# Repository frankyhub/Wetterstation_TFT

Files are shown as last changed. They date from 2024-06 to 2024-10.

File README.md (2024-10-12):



<div align="center">

|[:skull:ISSUE](https://github.com/frankyhub/Wetterstation_TFT/issues?q=is%3Aissue)|[:speech_balloon: Forum /Discussion](https://github.com/frankyhub/Wetterstation_TFT/discussions)|[:grey_question:WiKi](https://github.com/frankyhub/Wetterstation_TFT/wiki)||
|--|--|--|--|
| | | | |
||<a href="https://github.com/frankyhub/Wetterstation_TFT/issues">|<a href="https://github.com/frankyhub/Wetterstation_TFT/discussions">|<a href="https://github.com/frankyhub/Wetterstation_TFT/releases">|
|| <a href="https://github.com/frankyhub/Wetterstation_TFT/pulse" alt="Activity">| <a href="https://github.com/frankyhub/Wetterstation_TFT/graphs/traffic">  |<a href="https://github.com/frankyhub?tab=stars"> |
</div>

# Wetterstation_TFT
ESP32 Wetterstation mit WLAN-Manager - Wetterdaten Tegernsee und Raumklima, 1.77" TFT Display

## Story:
Diese Anleitung beschreibt den Aufbau einer Wetterstation in einem Holzgehäuse mit einem ESP32. Beim ESP32 ist ein DHT11-Sensor und einem TFT Display 1.77" angeschlossen. Die Wetterstation beinhaltet einen WiFi-Manager für die Einstellung der WLAN-Zugangsdaten (SSID und Passwort). Nach den ersten Start der Wetterstation, muss in den WLAN-Einstellungen des Handy oder Tablet das Netzwerk "Wetterstation" ausgewählt und über einen Browser die IP-Adresse 192.168.4.1 aufgerufen werden. Danach startet die "Wetterstation WLAN-Einstellung" und die Zugangsdaten für das WLAN können eingetragen werden. Sind die Zugangsdaten korrekt, startet die Wetterstation.
Die Wetterstation zeigt beim Start für 5 Sekunden einen Smiley. In dieser Zeit werden die aktuelle Uhrzeit, das Datum und die aktuellen Wetterdaten aus der Region Tegernsee von de.pool.ntp.org und von openweathermap.org geladen.
Sind die Daten geladen, verschwindet der Smiley und es werden in regelmäßigen Abständen drei Seiten mit Datum und Uhrzeit, danach das Raumklima mit Temperatur und Luftfeuchte, zuletzt die Wetterdaten Außen-Temperatur, Windgeschwindigkeit und Luftdruck angezeigt.

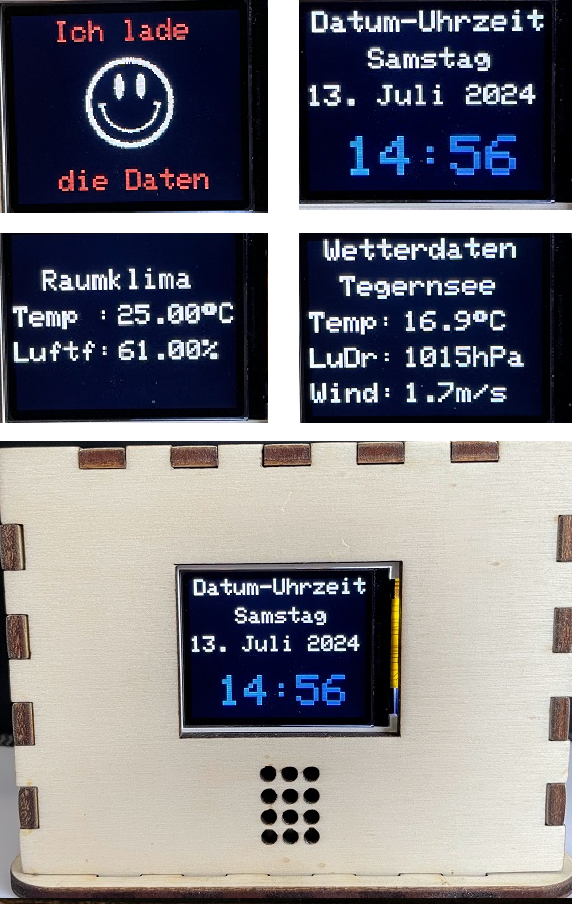
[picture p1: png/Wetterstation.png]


## Hardware:
Das benötigen wir für die Wetterstation:

| Anzahl | Bezeichnung | 
| --- | --- |
| 1 | ESP32 |
| 1 | ESP32-Shield | 
| 1 | ESP32 Stiftleiste | 
| 1 | DHT11-Sensor | 
| 1 | 10k Widerstand | 
| 1 | TFT Display 1.77" | 
| 1 | 8V Netzteil | 
| 1 | Sperrholzplatte 4mm x 600x300 | 
| 1 | 3D-Druck Teile für den ESP32, das OLED-Display und den DHT11 | 
| 1 | Schaltdraht | 
| 1 | Sekundenkleber | 
| 1 | Holzkleber |
| -------- | -------- | 

## Der Aufbau erfolgt in 5 Schritten:

1. Schritt Verdrahten

+ Wir löten auf das ESP32-Shield die Stiftleisten
+ Am ESP32-Shield wird ein 10kΩ Pullupwiderstand gegen +5V angelötet
+ Wir schließen mit Schaltdraht den DHT11-Sensor am ESP32-Shield GPIO27 an
+ Wir verdrahten den DHT11 mit +5V und GND
+ Wir verbinden mit Schaltdraht den ESP32 mit dem Display
+ Ist der ESP32 auf dem Shield, der Sensor und das Display angelötet, erfolgt der erste Test

| ESP32 | 1.77" TFT | 
| --- | --- |
|  GND | GND |
| 5V |  VCC |
|  G18 |  SCK |
| G23 |  SDA (MOSI) |
| G14 |  RES (RST) |
| G13 |  RS (DC) |
| G12 |  CS |
| 3.3V | LEDA |
| --- | ---  |

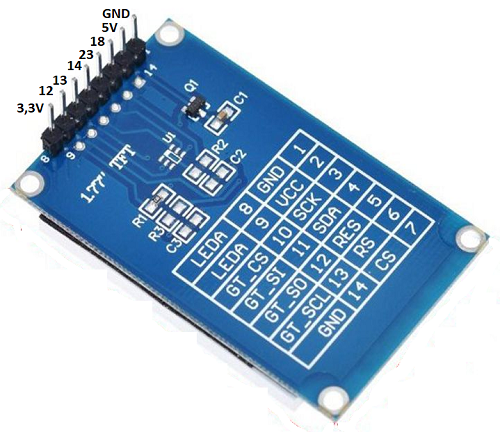
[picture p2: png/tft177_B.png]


| ESP32 | 1.8" TFT | 
| --- | --- |
|  GND | GND |
| 5V |  VCC |
|  G18 |  SCK |
| G23 |  SDA (MOSI) |
| G14 |  RESET |
| G13 |  A0 |
| G12 |  CS |
| 3.3V | LED |
| --- | ---  |

Stiftleisten einlöten:
  
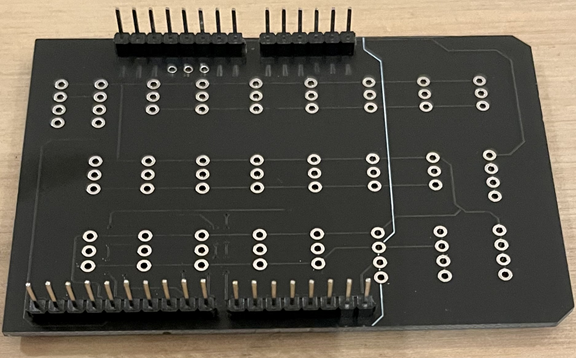
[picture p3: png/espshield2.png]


DHT11 anlöten:

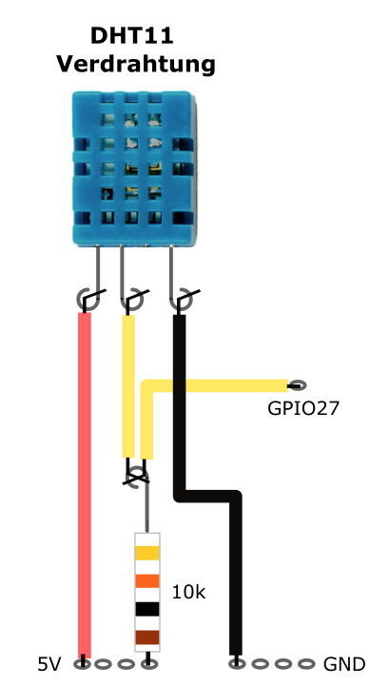
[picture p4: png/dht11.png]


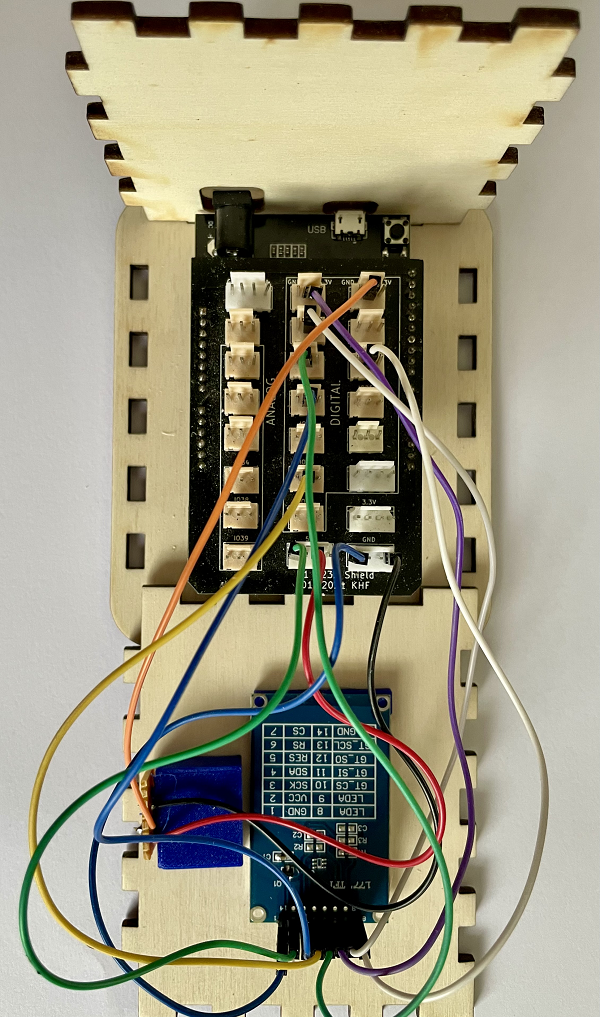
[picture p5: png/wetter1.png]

---

2. Schritt 3D-Druckteile zeichnen und drucken

+ 3D-Druckteile zeichnen und drucken
+ 4 x ESP32-Pins d=5mm h=7mm
+ 1 x DHT11-Halterung 24x8x21 mit DHT11 Aussparung

---

3. Schritt Gehäuse lasern

+ Wir erstellen mit [BOXES.PY](https://festi.info/boxes.py/) eine Lasercutter Vorlage
+ Wähle die ClosedBox - Fully closed box mit den Maßen x=110, y=90, h=90 und thickness=4
+ Zusätzlich werden runde Öffnungen für den DHT11-Sensor in der Frontseinte,
+ eine Aussparung für das TFT-Display und
+ zwei Aussparungen für den Spannungs- und Programmieranschluss des ESP32 in der Seitenwand eingefügt

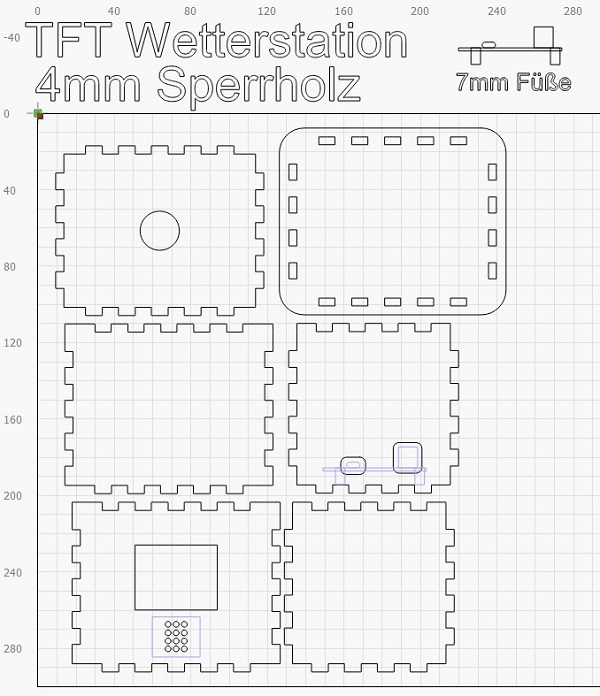
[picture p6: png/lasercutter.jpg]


---

4. Schritt Montage

+ Mit Sekundenkleber die 3D-Druck Bauteilfüße auf den ESP32 kleben
+ Das TFT-Display auf die Frontseite kleben
+ Die DHT11-Halterung an die Front-Innenseite kleben
+ Den ESP32 zu den Aussparungen der Seitenwand justieren und auf die Grundplatte kleben
+ Vor dem finalen verkleben des Gehäuses erfolgt ein Funktionstest
+ War der Funktionstest erfolgreich, kann das Gehäuse vollständig verklebt werden

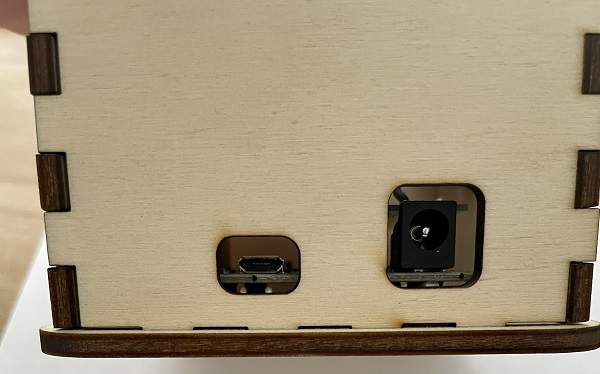
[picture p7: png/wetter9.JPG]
  

Erster Funktionstest am Seriellen Monitor:

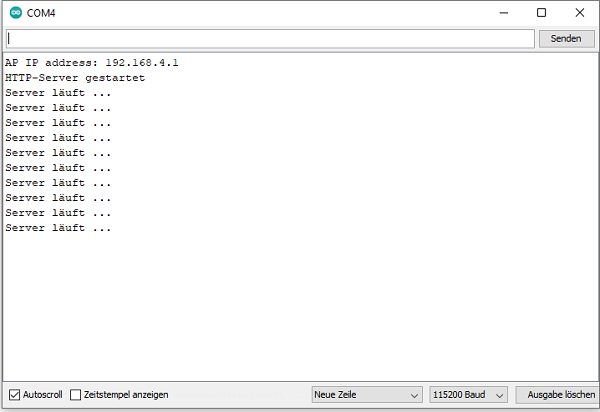
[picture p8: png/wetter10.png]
  

---

5. Schritt Inbetriebnahme

+ Im Handy oder Tablet die WLAN-Einstellungen öffnen
+ Das Netzwerk "Wetterstation" aufrufen
+ Im Browser die IP-Adresse 192.168.4.1 aufrufen
+ Die Seite "Wetterstation WLAN Einstellung" öffnet sich
+ Die WLAN-Zugangsdaten SSID und Passwort eingeben und speichern
+ Der Zeitserver ist voreingestellt und muss nicht verändert werden
+ Ist die WLAN-Verbindung korrekt, startet die Wetterstation mit einem Smiley am Display
+ Danach werden abwechselnd das aktuelle Datum mit Uhrzeit, danach das Raumklima mit Temperatur und Luftfeuchte und die aktuellen Wetterdaten aus der Region Tegernsee angezeigt
+ Die angezeigten Daten wechseln in regelmäßigen Abständen

Aufruf "Wetterstation" in den WLAN-Einstellungen

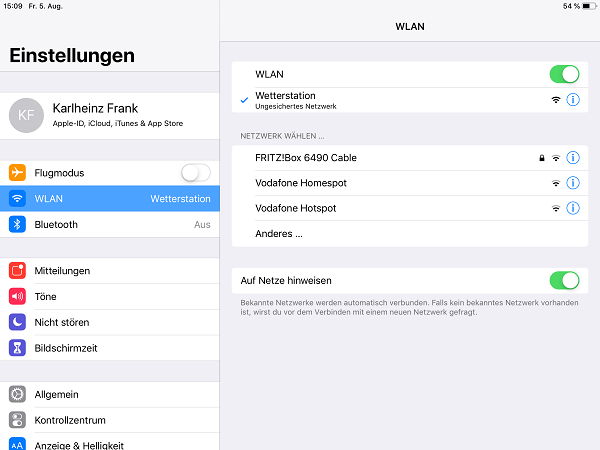
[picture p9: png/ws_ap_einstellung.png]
  

Im Browser die IP-Adresse 192.168.4.1 öffnen, die WLAN Zugangsdaten eingeben und speichern

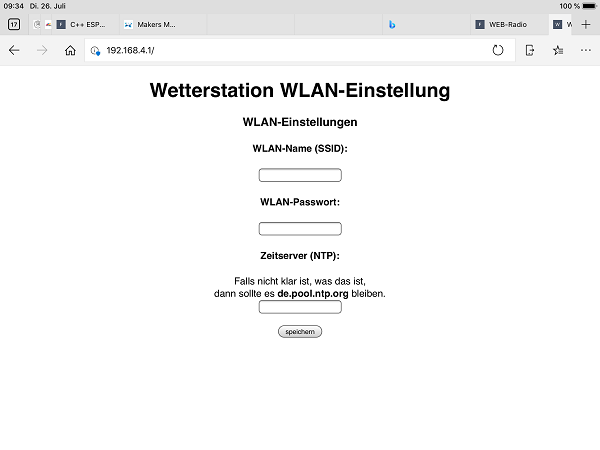
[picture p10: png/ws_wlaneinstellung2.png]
  

Sind die WLAN-Zugangsdaten korrekt, startet die Wetterstation

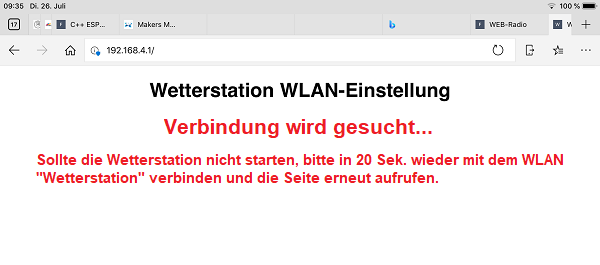
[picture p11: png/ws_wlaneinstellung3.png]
  

Startet die Wetterstation nicht, muss der Vorgang wiederholt werden.
Kontrolle am Seriellen Monitor:

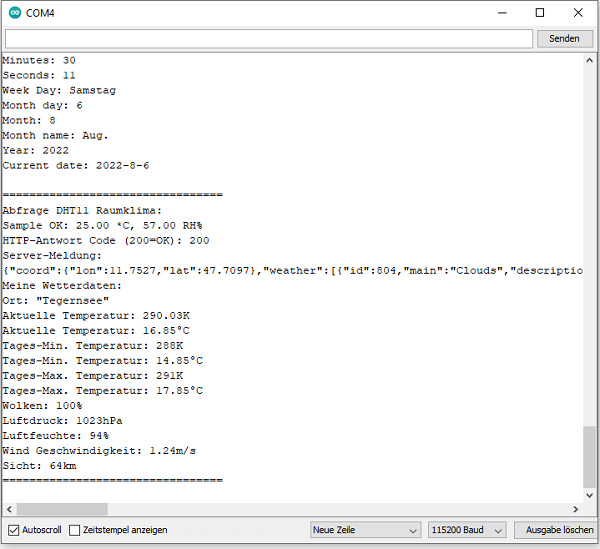
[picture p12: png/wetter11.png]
  

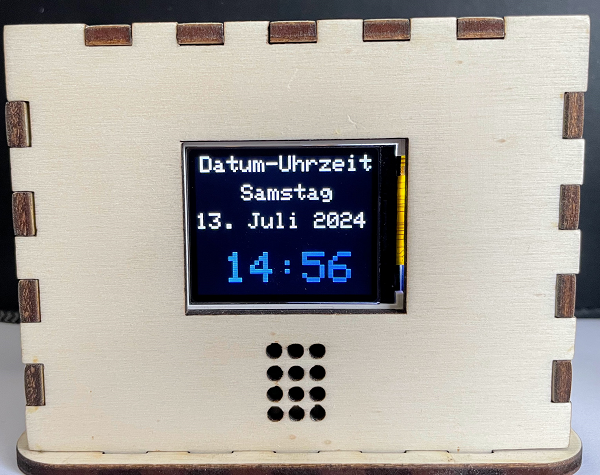
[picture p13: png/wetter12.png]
  

Fertig, Glückwunsch!

---

## Troubleshooting, mögliche Fehlerursachen

+ Sichtkontrolle - sind alle Lötstellen ok?
+ Sind Lötbrücken zusehen oder sind Bauteilfüße fälschlicherweise mit einander verbunden?
+ Sitzt der ESP32 korrekt auf dem Shield? Auf die Polung achten und und Bauteilfüße kontrollieren.
+ Sind die Anschlussdrähte zum Sensor und Display ok?
+ Ist die Spannungsversorgung für den ESP32 ok?
+ Wurde das Programm korrekt geladen? Meldung: Hochladen abgeschlossen.
+ Wird das Display vom ESP32 erkannt? Mit dem I²C-Scanner prüfen.
+ Werden die Sensordaten und die Uhrzeit/Datum ausgelesen? Mit dem Seriellen Montitor der Arduino IDE prüfen.
+ Wurden die WLAN-Zugangsdaten korrekt eingegeben?

---

## Abkürzungen

+ TFT Display -Thin-film transistor-Display, Anzeige mit Dünnschichttransistor-Ansteuerung
+ u8g2 Library - Universal 8Bit Graphics Library
+ I²C - Inter-Integrated Circuit (Serieller Datenbus)
+ SCL - Serial Clock
+ SDA - Serial Data

---

## Setup_User.h

Die Setup_User.h in C:\Users\User\Documents\Arduino\libraries\TFT_eSPI\ kopieren!!!!!

```C++
// TFT 1.77" 1.8" Library

#define ST7735_DRIVER
#define TFT_WIDTH 128
#define TFT_HEIGHT 160
#define ST7735_REDTAB
#define TFT_BACKLIGHT_ON HIGH // HIGH or LOW are options

// ###### EDIT THE PIN NUMBERS IN THE LINES FOLLOWING TO SUIT YOUR ESP32 SETUP ######
#define TFT_MOSI 23
#define TFT_SCLK 18
#define TFT_CS 17 // Chip select control pin
#define TFT_DC 2 // Data Command control pin
#define TFT_RST 14 // Reset pin (could connect to RST pin)

#define LOAD_GLCD   // Font 1. Original Adafruit 8 pixel font needs ~1820 bytes in FLASH
#define LOAD_FONT2  // Font 2. Small 16 pixel high font, needs ~3534 bytes in FLASH, 96 characters
#define LOAD_FONT4  // Font 4. Medium 26 pixel high font, needs ~5848 bytes in FLASH, 96 characters
#define LOAD_FONT6  // Font 6. Large 48 pixel font, needs ~2666 bytes in FLASH, only characters 1234567890:-.apm
#define LOAD_FONT7  // Font 7. 7 segment 48 pixel font, needs ~2438 bytes in FLASH, only characters 1234567890:-.
#define LOAD_FONT8  // Font 8. Large 75 pixel font needs ~3256 bytes in FLASH, only characters 1234567890:-.
#define LOAD_GFXFF  // FreeFonts. Include access to the 48 Adafruit_GFX free fonts FF1 to FF48 and custom fonts

// Comment out the #define below to stop the SPIFFS filing system and smooth font code being loaded
// this will save ~20kbytes of FLASH
#define SMOOTH_FONT
#define SPI_FREQUENCY  27000000 // Actually sets it to 26.67MHz = 80/3

// Optional reduced SPI frequency for reading TFT
#define SPI_READ_FREQUENCY  20000000

// The XPT2046 requires a lower SPI clock rate of 2.5MHz so we define that here:
#define SPI_TOUCH_FREQUENCY  2500000

// Transactions are automatically enabled by the library for an ESP32 (to use HAL mutex)
// so changing it here has no effect

// #define SUPPORT_TRANSACTIONS

//-------- END ----------------

```

---

<div style="position:absolute; left:2cm; ">   
<ol class="breadcrumb" style="border-top: 2px solid black;border-bottom:2px solid black; height: 45px; width: 900px;"> <p align="center"><a href="#oben">nach oben</a></p></ol>
</div>  

---

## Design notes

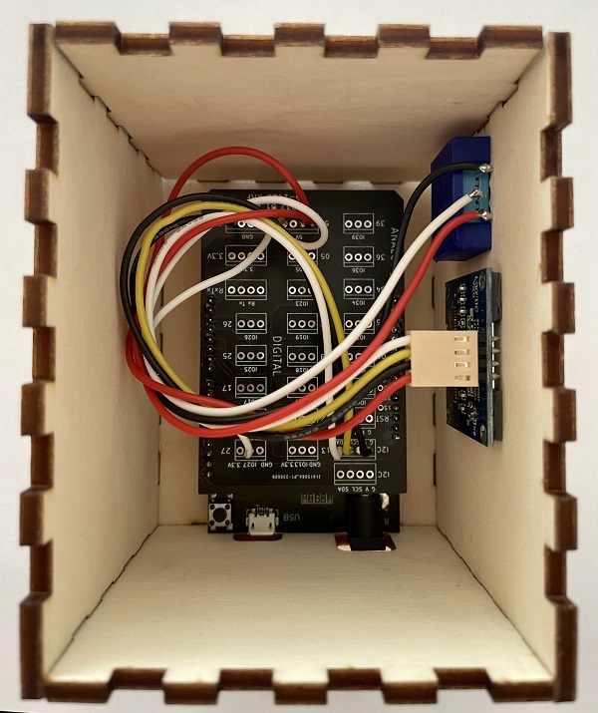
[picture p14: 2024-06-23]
png/wetter8.JPG

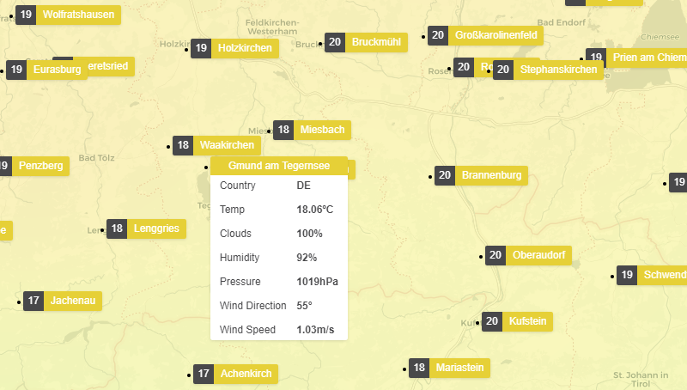
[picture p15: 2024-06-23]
png/13wetter.png

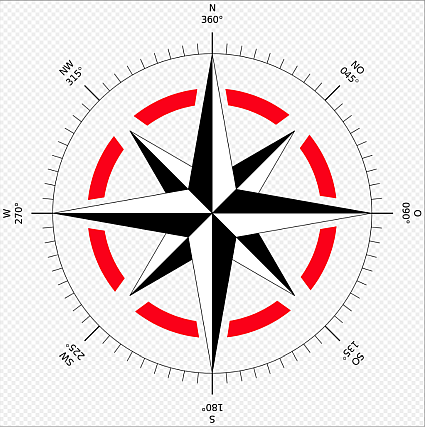
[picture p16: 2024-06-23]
png/14wetter.png

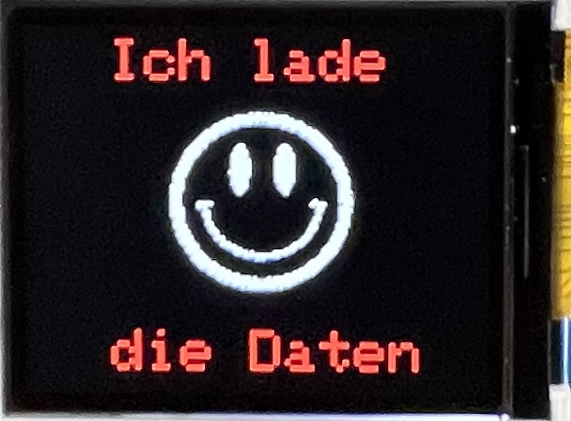
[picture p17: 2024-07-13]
png/ladedaten.png

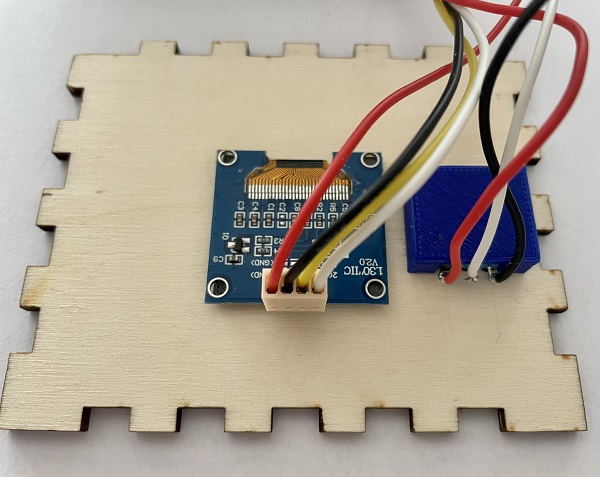
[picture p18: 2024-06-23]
png/wetter7.JPG

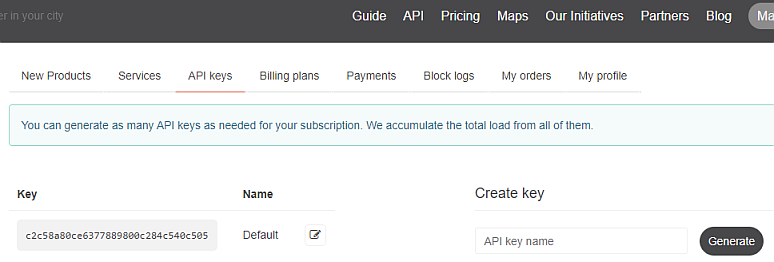
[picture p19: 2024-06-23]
png/11wetter.png

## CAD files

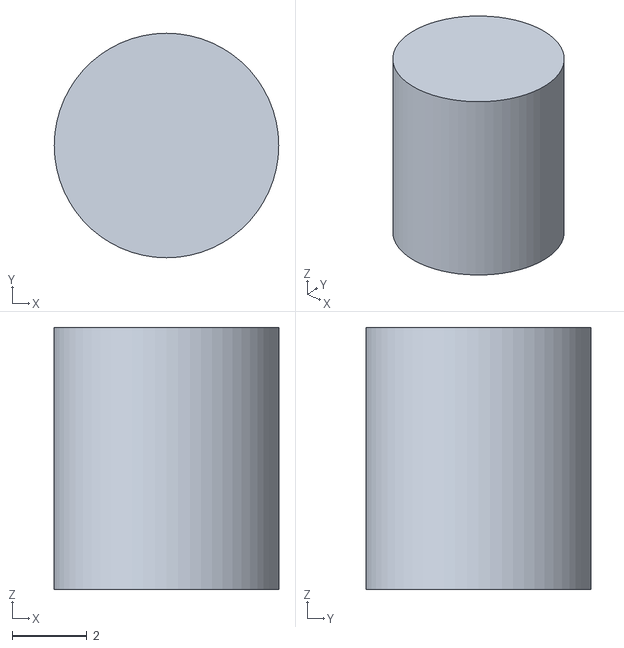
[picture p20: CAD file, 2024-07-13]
3D/ESP32-PIN7mm.stl
6.00 x 6.00 x 7.00

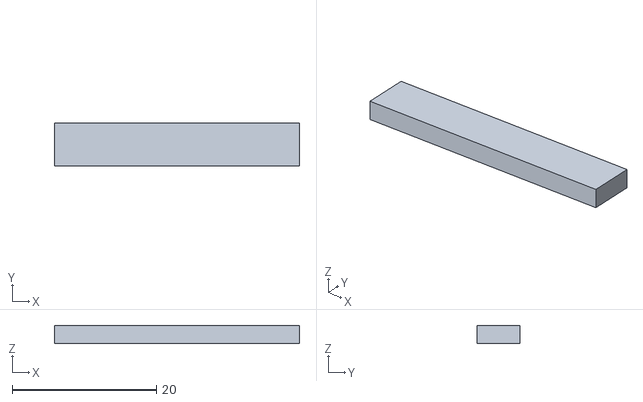
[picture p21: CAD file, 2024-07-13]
3D/TFT-Spacer.stl
34.0 x 6.00 x 2.50

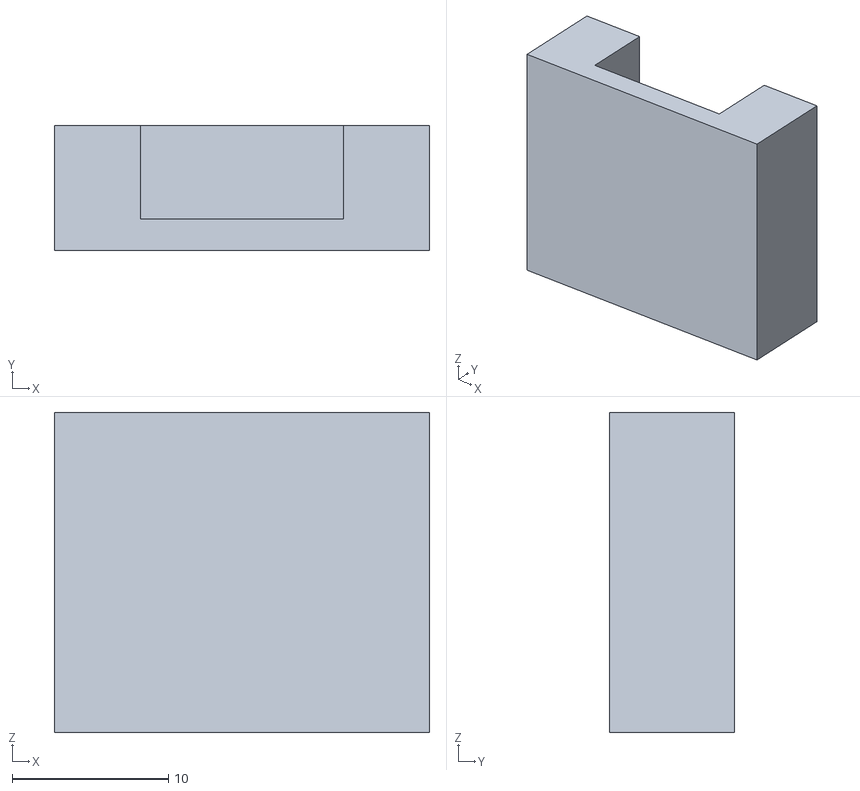
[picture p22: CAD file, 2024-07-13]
3D/DHT11-Halter.stl
24.0 x 8.00 x 20.5

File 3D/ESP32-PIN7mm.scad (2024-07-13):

//Platinen Pin ESP32 UNO Wetterstation
//4x

$fn=60;
Rgr = 3; //Radius PIN 
R1kl = 0; //Radius 1 Stift
R2kl = 0; //Radius 2 Stift
Sh = 7;       //Sockelhöhe


cylinder(h = Sh, r1=Rgr , r2=Rgr , center = true);
translate(v = [0, 0, Sh/2])
cylinder(h = 3, r1 = R1kl, r2 = R2kl, center = true);

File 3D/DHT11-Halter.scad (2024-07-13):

//DHT11-Halterung

difference() {
cube(size = [24,8,20.5], center = true);

translate(v = [-6.5, -2, -8])
cube(size = [13,7,18.5]);
   
}

/*
translate(v = [-12, -4, 10])
cube(size = [24,4,1.5]);

translate(v = [-10, -2, -8])
color( "red", 1.0 )
cube(size = [12.5,5.8,18]);
*/

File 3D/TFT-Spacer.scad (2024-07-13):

cube(size = [34,6,2.5], center = true);

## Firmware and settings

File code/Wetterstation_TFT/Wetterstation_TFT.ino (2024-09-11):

/*************************************************************************************************
                                      PROGRAMMINFO
**************************************************************************************************
  Funktion: ESP32 Wetterstation mit WLAN-Manager - Wetterdaten Tegernsee und Raumklima DHT11 TFT 1.77"
            Gas-Sensor MQ135, Buzzer und Gas LED-Ampel
            Automatische So/Wi-Zeit Umstelung
  OpenWeather API 31.10.2022: Wetterstation_AP    b2bc7fc61c4cc3545e6bbf151b58e1dd

**************************************************************************************************
  Version: 11.09.2024
**************************************************************************************************
  Board: ESP32vn IoT UNO V1.0.4 /1.0.6

**************************************************************************************************
  C++ Arduino IDE V1.8.19
**************************************************************************************************
  Einstellungen:
  https://dl.espressif.com/dl/package_esp32_index.json
  http://dan.drown.org/stm32duino/package_STM32duino_index.json
  https://raw.githubusercontent.com/espressif/arduino-esp32/gh-pages/package_esp32_dev_index.json
**************************************************************************************************

  Server-Abfrage Programm:
  http://api.openweathermap.org/data/2.5/weather?q=Tegernsee,DE&APPID=c2c58a80ce6377889800c284c540c505

  Server-Abfrage 2. API:
  http://api.openweathermap.org/data/2.5/weather?q=Tegernsee,DE&APPID=b2bc7fc61c4cc3545e6bbf151b58e1dd

  JSON-Meldung:
  {"coord":{"lon":11.7527,"lat":47.7097},
  "weather":
  [{"id":804,"main":"Clouds","description":"overcast clouds","icon":"04d"}],

  "base":"stations",
  "main":
  {"temp":288.35,
  "feels_like":288.54,
  "temp_min":285.19,
  "temp_max":291.7,
  "pressure":1016,
  "humidity":100,
  "sea_level":1016,
  "grnd_level":932},
  "visibility":273,
  "wind":{"speed":1.75,"deg":30,"gust":3.01},

  "clouds":{"all":100},
  "dt":1625628595,
  "sys":{"type":2,"id":2001431,"country":"DE","sunrise":1625628176,"sunset":1625685150},
  "timezone":7200,"id":2823679,"name":"Tegernsee","cod":200


  *********************************************  MQ-135 Luftqualität-Sensor  ******************************************************
  Beschreibung des MQ-135 Luftqualität-Sensor

  Sensor zum Messen der Konzentration von verschiedenen Giftgasen wie Benzon, Alkohol, Rauch sowie
  Verunreinigungen in der Luft. Der MQ-135 misst eine Gaskonzentration von 10 bis 1000ppm und ist ideal zum Erkennen eines
  Gaslecks, als Gas-Alarm oder für sonstige Robotik- und Microcontroller-Projekte.

  Die Sensoren der MQ-Serie benutzen ein kleines Heizelement mit einem elektronisch-chemischen Sensor. Sie sind empfindlich
  gegenüber verschiedenster Gase und eignen sich zur Verwendung in Räumen.

  Der Sensor hat eine hohe Empfindlichkeit und schnelle Reaktionszeit, benötigt allerdings einige Minuten bis er genaue Messwerte
  ausgibt, da der Sensor sich erst aufheizen muss. Die Messwerte des Sensors werden als analoger Wert ausgegeben, welcher mit einem
  Microcontroller einfach ausgewertet werden kann.

  Pinbelegung:

  VCC - Stromversorgung 5V
  GND - Masseanschluss
  AOUT - Analoger Output
  DOUT -  Digitaler Output
  Zum Einstellen des Schwellenwerts besitzt das Modul ein Potentiometer. Am digitalen Pin gibt der Sensor lediglich eine 0 oder 1 aus,
  je nach dem ob der eingestellte Schwellenwert überschritten wird.

  Vorsicht: Der Sensor wird im Betrieb warm!

  Details:
  Auflösung: 10~1000ppm
  Sensitive Widerstand: 2KΩ to 20KΩ in 100ppm CO
  Genauigkeit: ≥ 3%
  Reaktionszeit: ≤ 1s
  Ansprechzeit nach Einschalten: ≤ 30s
  Heizstrom: ≤ 180mA
  Heizspannung: 5.0V±0.2V / 1.5±0.1V
  Eingangsspannung: 5V
  Heizenergieleistung ca.: 350mW
  Abmessungen: ca. 30mm (Länge) * 20mm (Breite)


  !!!!!!!!!!!!!!!!! /TFT_eSPI/User_Setup.h !!!!!!!!!!!!!!!!!!!!!!!!!!!!!!!!!!!!!!

  // TFT 1.77" Library

  #define ST7735_DRIVER
  #define TFT_WIDTH 128
  #define TFT_HEIGHT 160
  #define ST7735_REDTAB
  #define TFT_BACKLIGHT_ON HIGH // HIGH or LOW are options

  // ###### EDIT THE PIN NUMBERS IN THE LINES FOLLOWING TO SUIT YOUR ESP32 SETUP ######
  #define TFT_MOSI 23
  #define TFT_SCLK 18
  #define TFT_CS 12 // Chip select control pin
  #define TFT_DC 13 // Data Command control pin
  #define TFT_RST 14 // Reset pin (could connect to RST pin)

  #define LOAD_GLCD   // Font 1. Original Adafruit 8 pixel font needs ~1820 bytes in FLASH
  #define LOAD_FONT2  // Font 2. Small 16 pixel high font, needs ~3534 bytes in FLASH, 96 characters
  #define LOAD_FONT4  // Font 4. Medium 26 pixel high font, needs ~5848 bytes in FLASH, 96 characters
  #define LOAD_FONT6  // Font 6. Large 48 pixel font, needs ~2666 bytes in FLASH, only characters 1234567890:-.apm
  #define LOAD_FONT7  // Font 7. 7 segment 48 pixel font, needs ~2438 bytes in FLASH, only characters 1234567890:-.
  #define LOAD_FONT8  // Font 8. Large 75 pixel font needs ~3256 bytes in FLASH, only characters 1234567890:-.
  #define LOAD_GFXFF  // FreeFonts. Include access to the 48 Adafruit_GFX free fonts FF1 to FF48 and custom fonts

  // Comment out the #define below to stop the SPIFFS filing system and smooth font code being loaded
  // this will save ~20kbytes of FLASH
  #define SMOOTH_FONT
  #define SPI_FREQUENCY  27000000 // Actually sets it to 26.67MHz = 80/3

  // Optional reduced SPI frequency for reading TFT
  #define SPI_READ_FREQUENCY  20000000

  // The XPT2046 requires a lower SPI clock rate of 2.5MHz so we define that here:
  #define SPI_TOUCH_FREQUENCY  2500000

  // Transactions are automatically enabled by the library for an ESP32 (to use HAL mutex)
  // so changing it here has no effect

  // #define SUPPORT_TRANSACTIONS

 **************************************************************************************************/


#include <Arduino.h>
#include <U8g2lib.h>
#include <Wire.h>


U8G2_SH1106_128X64_NONAME_F_HW_I2C u8g2(U8G2_R0, /* reset=*/ U8X8_PIN_NONE);
unsigned long delayTime;

//******** TFT ************************************
// New background colour
#define TFT_BROWN 0x38E0

// Pause in milliseconds between screens, change to 0 to time font rendering
#define WAIT 2000

#include <TFT_eSPI.h> // Graphics and font library for ST7735 driver chip
#include <SPI.h>
TFT_eSPI tft = TFT_eSPI();  // Aktualisiere User_Setup.h

unsigned long targetTime = 0; // Used for testing draw times

//******** DHT ************************************
#include <SimpleDHT.h> //by Winlin 1.0.14       
int pinDHT11 = 27;
SimpleDHT11 dht11(pinDHT11);
#include <Adafruit_Sensor.h> //by Adafruit 0.8.0
#include <WiFi.h> //by Arduino 1.2.7
#include <WiFiUdp.h>
#include <NTPClient.h> //Easy NTPC ba Harshen Alva 1.1.0

//*************************************************

#include <HTTPClient.h> //Arduino HTTPClient by Arduino 0.4.0
#include <Arduino_JSON.h> //by Arduino 0.1.0

//*************************************************
//------- Gas Sensor MQ135 ------------
int Buzzer = 26;
int Gas_analog = 39;
//int Gas_digital = 2;

#define led_rot 25
#define led_gelb 17
#define led_gruen 16
//----------------------------------------


//*************************************************
String openWeatherMapApiKey = "b2bc7fc61c4cc3545e6bbf151b58e1dd"; //Workshop API


String city = "Tegernsee";
String countryCode = "DE";

unsigned long lastTime = 0;
unsigned long timerDelay = 10000; //120 Sekunden
String jsonBuffer;
//*************************************************


//-----------------------------------------------
int ktemp;
int mintemp;
int maxtemp;
int sicht;

//----------------clock----------------------------
// Internetzeit
#define MY_NTP_SERVER "de.pool.ntp.org"
#define MY_TZ "CET-1CEST,M3.5.0/02,M10.5.0/03" // https://github.com/nayarsystems/posix_tz_db/blob/master/zones.csv
//#include <time.h> // time() ctime()
time_t now;    // this is the epoch
tm tm;         // the structure tm holds time information in a more convenient way
void showTime() {
  time(&now); // read the current time
  localtime_r(&now, &tm); // update the structure tm with the current time
  Serial.print("year:");
  Serial.print(tm.tm_year + 1900); // years since 1900
  Serial.print("\tmonth:");
  Serial.print(tm.tm_mon + 1); // January = 0 (!)
  Serial.print("\tday:");
  Serial.print(tm.tm_mday); // day of month
  Serial.print("\thour:");
  Serial.print(tm.tm_hour); // hours since midnight 0-23
  Serial.print("\tmin:");
  Serial.print(tm.tm_min); // minutes after the hour 0-59
  Serial.print("\tsec:");
  Serial.print(tm.tm_sec); // seconds after the minute 0-61*
  Serial.print("\twday");
  Serial.print(tm.tm_wday); // days since Sunday 0-6
  if (tm.tm_isdst == 1) // Daylight Saving Time flag
    Serial.print("\tDST");
  else
    Serial.print("\tstandard");
  Serial.println();
}



// Define NTP Client to get time

WiFiUDP ntpUDP;
NTPClient timeClient(ntpUDP, "de.pool.ntp.org");

//Week Days
String weekDays[7] = {"Sonntag", "Montag", "Dienstag", "Mittwoch", "Donnerstag", "Freitag", "Samstag"};

//Month names
String months[12] = {"Jan.", "Feb.", "M""\xE4""rz", "Apr.", "Mai", "Juni", "Juli", "Aug.", "Sep.", "Okt.", "Nov.", "Dez."};
//-----------------------------------------------



void setup() {

  u8g2.begin();

  int BildschirmBreite = u8g2.getDisplayWidth();
  int BildschirmHoehe = u8g2.getDisplayHeight();

  //Smiley XBM erstellt mit GIMP
#define smiley_width 64
#define smiley_height 64
  static unsigned char smiley[] = {
    0x00, 0x00, 0x00, 0xd0, 0x0a, 0x00, 0x00, 0x00, 0x00, 0x00, 0x80, 0xff,
    0xff, 0x01, 0x00, 0x00, 0x00, 0x00, 0xf0, 0xff, 0xff, 0x07, 0x00, 0x00,
    0x00, 0x00, 0xfc, 0x5f, 0xfd, 0x3f, 0x00, 0x00, 0x00, 0x00, 0xff, 0x00,
    0x80, 0x7f, 0x00, 0x00, 0x00, 0x80, 0x1f, 0x00, 0x00, 0xfc, 0x01, 0x00,
    0x00, 0xe0, 0x07, 0x00, 0x00, 0xe0, 0x07, 0x00, 0x00, 0xf0, 0x01, 0x00,
    0x00, 0xc0, 0x0f, 0x00, 0x00, 0xf8, 0x00, 0x00, 0x00, 0x00, 0x1f, 0x00,
    0x00, 0x3c, 0x00, 0x00, 0x00, 0x00, 0x3e, 0x00, 0x00, 0x1e, 0x00, 0x00,
    0x00, 0x00, 0x7c, 0x00, 0x00, 0x1f, 0x00, 0x03, 0x80, 0x01, 0xf8, 0x00,
    0x80, 0x07, 0x80, 0x03, 0xc0, 0x03, 0xf0, 0x00, 0xc0, 0x07, 0x80, 0x07,
    0xc0, 0x03, 0xe0, 0x01, 0xc0, 0x03, 0xc0, 0x07, 0xc0, 0x07, 0xc0, 0x03,
    0xe0, 0x01, 0xc0, 0x07, 0xe0, 0x07, 0x80, 0x07, 0xe0, 0x00, 0xc0, 0x0f,
    0xe0, 0x07, 0x80, 0x07, 0xf0, 0x00, 0xc0, 0x0f, 0xe0, 0x07, 0x00, 0x0f,
    0x70, 0x00, 0xc0, 0x0f, 0xe0, 0x07, 0x00, 0x0e, 0x78, 0x00, 0xc0, 0x0f,
    0xe0, 0x07, 0x00, 0x1e, 0x38, 0x00, 0xe0, 0x0f, 0xe0, 0x07, 0x00, 0x1e,
    0x3c, 0x00, 0xc0, 0x0f, 0xe0, 0x07, 0x00, 0x1c, 0x1c, 0x00, 0xc0, 0x07,
    0xe0, 0x07, 0x00, 0x3c, 0x1c, 0x00, 0xc0, 0x07, 0xe0, 0x07, 0x00, 0x38,
    0x1c, 0x00, 0xc0, 0x07, 0xc0, 0x03, 0x00, 0x38, 0x1e, 0x00, 0x80, 0x07,
    0xc0, 0x03, 0x00, 0x38, 0x1e, 0x00, 0x80, 0x03, 0x80, 0x01, 0x00, 0x38,
    0x0e, 0x00, 0x00, 0x01, 0x00, 0x01, 0x00, 0x78, 0x0e, 0x00, 0x00, 0x00,
    0x00, 0x00, 0x00, 0x38, 0x0e, 0x00, 0x00, 0x00, 0x00, 0x00, 0x00, 0x78,
    0x0e, 0x00, 0x00, 0x00, 0x00, 0x00, 0x04, 0x78, 0x0e, 0x7c, 0x00, 0x00,
    0x00, 0x00, 0x3e, 0x70, 0x0e, 0x1c, 0x00, 0x00, 0x00, 0x00, 0x18, 0x38,
    0x1e, 0x10, 0x00, 0x00, 0x00, 0x00, 0x18, 0x78, 0x1e, 0x30, 0x00, 0x00,
    0x00, 0x00, 0x08, 0x38, 0x1e, 0x30, 0x00, 0x00, 0x00, 0x00, 0x08, 0x38,
    0x1c, 0x20, 0x00, 0x00, 0x00, 0x00, 0x0c, 0x38, 0x1c, 0x20, 0x00, 0x00,
    0x00, 0x00, 0x04, 0x38, 0x1c, 0x60, 0x00, 0x00, 0x00, 0x00, 0x06, 0x3c,
    0x3c, 0x40, 0x00, 0x00, 0x00, 0x00, 0x06, 0x1c, 0x38, 0xc0, 0x00, 0x00,
    0x00, 0x00, 0x03, 0x1c, 0x78, 0x80, 0x01, 0x00, 0x00, 0x00, 0x01, 0x1e,
    0x78, 0x00, 0x01, 0x00, 0x00, 0x80, 0x01, 0x0e, 0xf0, 0x00, 0x07, 0x00,
    0x00, 0xc0, 0x00, 0x0f, 0xf0, 0x00, 0x04, 0x00, 0x00, 0x60, 0x00, 0x07,
    0xe0, 0x01, 0x1c, 0x00, 0x00, 0x38, 0x80, 0x07, 0xc0, 0x03, 0x70, 0x00,
    0x00, 0x0c, 0xc0, 0x03, 0xc0, 0x03, 0xc0, 0x01, 0x00, 0x07, 0xe0, 0x03,
    0x80, 0x07, 0x80, 0x17, 0xf0, 0x01, 0xe0, 0x01, 0x00, 0x0f, 0x00, 0xfc,
    0x3f, 0x00, 0xf0, 0x00, 0x00, 0x1f, 0x00, 0x40, 0x01, 0x00, 0x78, 0x00,
    0x00, 0x3e, 0x00, 0x00, 0x00, 0x00, 0x3e, 0x00, 0x00, 0xfc, 0x00, 0x00,
    0x00, 0x00, 0x1f, 0x00, 0x00, 0xf8, 0x01, 0x00, 0x00, 0x80, 0x0f, 0x00,
    0x00, 0xe0, 0x07, 0x00, 0x00, 0xe0, 0x07, 0x00, 0x00, 0xc0, 0x1f, 0x00,
    0x00, 0xf8, 0x03, 0x00, 0x00, 0x00, 0xff, 0x00, 0x00, 0xff, 0x00, 0x00,
    0x00, 0x00, 0xfe, 0x2f, 0xf4, 0x3f, 0x00, 0x00, 0x00, 0x00, 0xf8, 0xff,
    0xff, 0x0f, 0x00, 0x00, 0x00, 0x00, 0xc0, 0xff, 0xff, 0x03, 0x00, 0x00,
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
  };

  //************* TFT ****************************
  tft.init();
  tft.setRotation(1);
  tft.fillScreen(TFT_BLACK);
  tft.drawXBitmap(50, 30, smiley, 64, 64, 0xFFFF);
  tft.setTextSize (2);
        tft.setTextColor(TFT_BLUE, TFT_BLACK); 
  tft.drawString("Ich lade ", 30, 5);
  tft.drawString("die Daten", 30, 106);
    delay(500);
//***********************************************;


  Serial.begin(115200);
  //init WiFi
  Serial.println("Connecting to WiFi");
  while (!makeWLAN()) {
    Serial.println("Cannot connect :(");
    delay(1000);
  }
  //******** ESP32 Wi-So Zeit ***************
  Serial.println("\nNTP TZ DST - bare minimum");

#ifdef ARDUINO_ARCH_ESP32
  // ESP32 seems to be a little more complex:
  configTime(0, 0, MY_NTP_SERVER); // 0, 0 because we will use TZ in the next line
  setenv("TZ", MY_TZ, 1); // Set environment variable with your time zone
  tzset();
#else
  // ESP8266
  configTime(MY_TZ, MY_NTP_SERVER); // --> for the ESP8266 only
#endif



  //------- Gas Sensor MQ135 ------------
  pinMode(Buzzer, OUTPUT);
  //    pinMode(Gas_digital, INPUT);

  pinMode(led_rot, OUTPUT);
  pinMode(led_gruen, OUTPUT);
  pinMode(led_gelb, OUTPUT);
  //----------------------------------------

  Serial.println("Aktualisierung ist auf 10 Sekunden eingestellt.");

  // Initialize a NTPClient to get time
  timeClient.begin();
  // Set offset time in seconds to adjust for your timezone, for example:
  // GMT +1 = 3600 Winterzeit
  // GMT +2 = 7200 Sommerzeit
  //  timeClient.setTimeOffset(3600);

}



void loop() {
  Serial.print("SO-WI-Zeit Anfang: ");
  showTime();
  Serial.print("Epoch Time: ");
  Serial.print("SO-WI-Zeit Ende: ");

  //----------------Clock-----------------------------------------
  timeClient.update();

  time_t epochTime = timeClient.getEpochTime();
  Serial.print("Epoch Time: ");
  Serial.println(epochTime);

  String formattedTime = timeClient.getFormattedTime(); //!!!!!!!!!!!!!!!!!!!!!!!!!!!!!!!!!!!!!!!!!!!!!!!!!!!!!!!!!!!!!!!!!!!!!!!!!!!!!!!!!
  Serial.print("Formatted Time: ");
  Serial.println(formattedTime);

  int currentHour = timeClient.getHours();
  Serial.print("Hour: ");
  Serial.println(currentHour);

  int currentMinute = timeClient.getMinutes();
  Serial.print("Minutes: ");
  Serial.println(currentMinute);

  int currentSecond = timeClient.getSeconds();
  Serial.print("Seconds: ");
  Serial.println(currentSecond);

  String weekDay = weekDays[timeClient.getDay()];
  Serial.print("Week Day: ");
  Serial.println(weekDay);

  //Get a time structure
  struct tm *ptm = gmtime ((time_t *)&epochTime);

  int monthDay = ptm->tm_mday;
  Serial.print("Month day: ");
  Serial.println(monthDay);


  int currentMonth = ptm->tm_mon + 1;
  Serial.print("Month: ");
  Serial.println(currentMonth);

  String currentMonthName = months[currentMonth - 1];
  Serial.print("Month name: ");
  Serial.println(currentMonthName);

  int currentYear = ptm->tm_year + 1900;
  Serial.print("Year: ");
  Serial.println(currentYear);

  //Print complete date:
  String currentDate = String(currentYear) + "-" + String(currentMonth) + "-" + String(monthDay);
  Serial.print("Current date: ");
  Serial.println(currentDate);

  Serial.println("");

  //---------------------------------------------------------


  Serial.println("=================================");
  Serial.println("Abfrage DHT11 Raumklima:");
  float temperature = 0;
  float humidity = 0;
  int err = SimpleDHTErrSuccess;
  if ((err = dht11.read2(&temperature, &humidity, NULL)) != SimpleDHTErrSuccess) {
    Serial.print("Read DHT11 failed, err=");
    Serial.println(err);
    delay(2000);
    return;
  }



  Serial.print("Sample OK: ");
  Serial.print((float)temperature - 3);
  Serial.print(" *C, ");
  Serial.print((float)humidity);
  Serial.println(" RH%");
  delay(5000); // DHT11 Abfragezeit

  if ((millis() - lastTime) > timerDelay) {
    // Check WiFi Status
    if (WiFi.status() == WL_CONNECTED) {
      String serverPath = "http://api.openweathermap.org/data/2.5/weather?q=" + city + "," + countryCode + "&APPID=" + openWeatherMapApiKey;

      jsonBuffer = httpGETRequest(serverPath.c_str());
      Serial.println(jsonBuffer);
      JSONVar myObject = JSON.parse(jsonBuffer);

      if (JSON.typeof(myObject) == "undefined") {
        Serial.println("Eingabe fehlgeschlagen!");
        return;
      }
      ktemp = (myObject["main"]["temp"]);
      mintemp = (myObject["main"]["temp_min"]);
      maxtemp = (myObject["main"]["temp_max"]);

      //      Serial.print("JSON object = ");
      Serial.println("Meine Wetterdaten:");
      Serial.print("Ort: ");
      Serial.println(myObject["name"]);
      Serial.print("Aktuelle Temperatur: ");
      Serial.print(myObject["main"]["temp"]);
      Serial.println("K ");
      Serial.print("Aktuelle Temperatur: ");
      Serial.print(ktemp - 273.15);
      Serial.println("°C ");
      Serial.print("Tages-Min. Temperatur: ");
      Serial.print(mintemp);
      Serial.println("K ");

      Serial.print("Tages-Min. Temperatur: ");
      Serial.print(mintemp - 273.15);
      Serial.println("°C ");

      Serial.print("Tages-Max. Temperatur: ");
      Serial.print(maxtemp);
      Serial.println("K ");

      Serial.print("Tages-Max. Temperatur: ");
      Serial.print(maxtemp - 273.15);
      Serial.println("°C ");

      Serial.print("Wolken: ");
      Serial.print(myObject["clouds"]["all"]);
      Serial.println("% ");

      Serial.print("Luftdruck: ");
      Serial.print(myObject["main"]["pressure"]);
      Serial.println("hPa");
      Serial.print("Luftfeuchte: ");
      Serial.print(myObject["main"]["humidity"]);
      Serial.println("% ");
      Serial.print("Wind Geschwindigkeit: ");
      Serial.print(myObject["wind"]["speed"]);
      Serial.println("m/s ");

      sicht = (myObject["visibility"]);
      sicht = sicht / 100;
      Serial.print("Sicht: ");
      Serial.print(sicht);
      Serial.println("km ");

      //---------------------------------------------------------


      //------- Gas Sensor MQ135 ------------
      int gassensorAnalog = analogRead(Gas_analog);
      //  int gassensorDigital = digitalRead(Gas_digital);
      delay(100);


      Serial.print("Gas Sensor: ");
      Serial.println(gassensorAnalog);
      //  Serial.println("\t");
      //  Serial.print(gassensorDigital);
      //  Serial.print("\t");
      //  Serial.print("\t");

      if (gassensorAnalog <= 550)  {
        Serial.println("=================================");
        Serial.println("kein Gas");
        Serial.println("=================================");
        digitalWrite(led_gruen, HIGH);        // OK
      } else {
        digitalWrite(led_gruen, LOW);
      }


      if (gassensorAnalog >= 551 && gassensorAnalog <= 799) {
        digitalWrite(led_gelb, HIGH);
        Serial.println("=================================");
        Serial.println("Gas erkannt");
        Serial.println("=================================");
      } else {
        digitalWrite(led_gelb, LOW);
      }



      if (gassensorAnalog > 800) {
        Serial.println("=================================");
        Serial.println("Gas-Alarm");
        Serial.println("=================================");
        digitalWrite(led_rot, HIGH);         // Gas-Alarm

        digitalWrite (Buzzer, HIGH) ; //send tone

      } else {
        digitalWrite(led_rot, LOW);
        digitalWrite (Buzzer, LOW) ;  //no tone
      }
      delay(100);
      //-----------------------------------------------------



      Serial.println("=================================");

      //********* TFT *****************
      tft.setTextSize (2);

      //---------- Seite 1 ----------------------------

      tft.fillScreen(TFT_BLACK);
      tft.setTextColor(TFT_WHITE, TFT_BLACK); //weiss
      tft.drawString("Datum-Uhrzeit", 5, 0);
      //  tft.drawString("Tegernsee", 22, 26);


      // tft.drawString("Temp :", 0, 52);
      tft.setCursor (22, 26);
      tft.print (weekDay);
      tft.setCursor (0, 52);
      tft.print(monthDay); tft.print(". "); tft.print (currentMonthName); tft.print(" "); tft.print (currentYear);
     

      tft.setCursor (25, 88); //20 , 88
      tft.setTextColor(0xFBE0, TFT_BLACK);
      tft.setTextSize (4);
      tft.print(tm.tm_hour);
     // tft.print(currentHour);
      tft.print(":");
      if (currentMinute < 10) {
        tft.print("0");
        tft.print(currentMinute);
      } else {
        tft.print(currentMinute);
      }
      tft.setTextSize (2);
      /*
        tft.drawString("Wind :", 0, 104);
         tft.setCursor (76,104);
        tft.print (w,1);tft.print ("m/s");
      */

      delay(4000);



      //---------- Seite 2 ----------------------------
      tft.fillScreen(TFT_BLACK);
      tft.setTextColor(TFT_WHITE, TFT_BLACK); //weiss
      tft.drawString("Wetterdaten", 12, 0);
      tft.drawString("Tegernsee", 22, 26);


      tft.drawString("Temp: ", 0, 52);
      tft.setCursor (65, 52);
      tft.print (maxtemp - 273.15, 1); tft.print ("\xF7""C");


      tft.drawString("LuDr: ", 0, 78);
      tft.setCursor (65, 78);
      tft.print (myObject["main"]["pressure"]); tft.print ("hPa");

      tft.drawString("Wind: ", 0, 104);
      tft.setCursor (65, 104);
      tft.print (myObject["wind"]["speed"]); tft.print ("m/s");

      delay(4000);
      
      //*******************************************
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

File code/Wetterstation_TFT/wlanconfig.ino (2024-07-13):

/* ***********************************************************************
 *  Dies dient zur Konfiguration und zum Aufbau einer WLAN-Verbindung
 *  
 *  - Laden der Zugangsdaten aus dem Flash
 *       - ssid
 *       - password
 *       - ntpserver
 *  - Versuch eine Verbindung mit diesen Anmeldeinformationen herzustellen
 *  - Wenn eine Verbindung möglich ist, wird folgendes passieren:
 *      - eine Änderung im AP-Modus (NICHT neu gestartet!!!)
 *      - Aufruf des WLAN-Managers http://192.168.4.1
 *      - zeigt HTML-Code aus wlanconf.h mit ausgefüllten Anmeldeinformationen an
 *      - Benutzer speichert die Zugangsdaten
 *      - Beim Absenden des Formulars per Absenden werden die Anmeldeinformationen in Flash aktualisiert (ONLÝ THEN*)
 *      - Startet im Stationsmodus neu und beginnt den nächsten Versuch, sich mit den neuen Zugangdaten zu verbinden
 *  => Dies geschieht unendlich, bis eine Verbindung hergestellt werden kann.
 *      
 *  Es wird beim Aufruf von "makeWLAN()" (usaly in 'setup()') verwendet.
 *  Es wirdt "true" zurückgegeben, wenn die Verbindung erfolgreich war
 *  
 *  Libraries:
 *    - Wifi.h
 *    - Preferences.h
 *    - ESPAsyncWebServer.h
 *  
 *  Die WLAN-Instanz heißt "WiFi"
 *  Die Webserver-Instanz (nur im AP-Modus) heißt "Server"
 *  
 *  Wenn TESTMODUS wahr ist, wird nach einer erfolgreichen Verbindung ein falsches Passwort in Flash gespeichert. Also
 *  es stellt nach dem nächsten Neustart keine Verbindung her und startet den Vorgang von Anfang an.
 *  
 *  *: Wenn das WLAN offline ist und der ESP32 deshalb nach neuen Daten fragt, kannst du es ignorieren.
 *     Starte den ESP32 neu, wenn dein WLAN wieder verfügbar ist. Die Anmeldeinformationen ändern sich erst, wenn
 *     sie neu abgespeichert wurden.
 */

#include <WiFi.h>
#include <Preferences.h>
#include "ESPAsyncWebServer.h" //PathVariableHandlers by Chris Mullins 2.0.0

#include "wlanconf.h"  //HTML-code fuer WLAN-setup

#define TESTMODUS false

// Webserver on port 80
AsyncWebServer server(80);

// WLAN credentials
Preferences preferences;
String ssid;
String password;
String ntpserver;
int    bootAsAP;
#define MAXWLANTRY 10  // AP-Modus nach neuen Anmeldeinformationen fragen

// ### Im 'setup() aufrufen'
int makeWLAN()
{
  preferences.begin("credentials", false);

  ssid = preferences.getString("ssid", ""); 
  password = preferences.getString("password", "");
  ntpserver = preferences.getString("ntpserver", "de.pool.ntp.org");
    
  delay(250);
  Serial.println(F("Wetterstation: "));
  Serial.println(ssid);

  int tryCount = 0;
  if (ssid == "" || password == ""){
    Serial.println("Keine WLAN-Logindaten gespeichert!");
    ssid = "blub"; password = "blah";
    tryCount = MAXWLANTRY;
  }

  if (tryCount < MAXWLANTRY) {
    // Mit Wi-Fi verbinden
    WiFi.mode(WIFI_STA);
    WiFi.begin(ssid.c_str(), password.c_str());
    Serial.print("Verbinde mit WiFi ..");
    while ((WiFi.status() != WL_CONNECTED) && (tryCount<MAXWLANTRY)) {
      Serial.print('.');
      delay(1000);
      tryCount++;
    }
    IPAddress lip(0,0,0,0);
    if (WiFi.localIP() == lip) {
      tryCount = MAXWLANTRY;
    }
  }

  if (tryCount < MAXWLANTRY) {
    Serial.print(F("IP-Adresse per DHCP ist "));
    Serial.println(WiFi.localIP());  
    // Für den Automatik-Test
    if (TESTMODUS) {
      preferences.putString("password", "XXX"); 
    }
    return(true);   // Wenn die Verbindung in Ordnung ist, stoppe hier und kehre zurück
  }

  // Wenn keine Verbindung möglich ist, starte die Konfigurationswebsite im AP-Moduse 
  makeConfigAP();

  return(false);    
                   
}


// ### Baut eine eigene "WLAN-Wetterstation" auf und startet unter http://192.168.4.1 ein Webinterface
// Diese Funktion läuft in der Schleife, bis neue Anmeldeinformationen gegeben sind - in diesem Fall startet sie neu
void makeConfigAP() {

  Serial.print("Erstelle AP (Access Point)…");
  WiFi.mode(WIFI_AP);
  delay(500);  
  WiFi.softAP("Wetterstation");

  IPAddress IP = WiFi.softAPIP();
  Serial.print("AP IP address: ");
  Serial.println(IP);
  
  server.on("/", HTTP_ANY, [](AsyncWebServerRequest *request){

    int paramsNr = request->params();
    Serial.println(paramsNr);
    String ssid = "";
    String password = "";
    int paramCountOk = 0;
    int gotAnswer = false;
  
    for(int i=0;i<paramsNr;i++){
  
      AsyncWebParameter* p = request->getParam(i);
      Serial.print("Param name: ");
      Serial.println(p->name());
      Serial.print("Param value: ");
      Serial.println(p->value());
      Serial.println("------");
      if (p->name() == "ssid") {
        ssid = p->value();
        paramCountOk++;
      }
      if (p->name() == "password") {
        password = p->value();
        paramCountOk++;
      }
      // is used for my clock-projects :) and
      // here commented out in HTML-code.
      if (p->name() == "ntpserver") {   
        ntpserver = p->value();
        paramCountOk++;
      }

      if (paramCountOk >= paramsNr) {
        preferences.putString("ssid", ssid); 
        preferences.putString("password", password); 
        preferences.putString("ntpserver", ntpserver); 
        preferences.putInt("bootAP", 0); 
        preferences.end();
        gotAnswer = true;
      }
    }
  
    String s = MAIN_page; //HTML-Inhalte lesen
    if (gotAnswer) {
      s.replace("*mark1begin*", "<!--");
      s.replace("*mark1end*", "-->");
      s.replace("*feedback*", "<div style='color:#CC0000'><h1>Verbindung wird versucht...</h1><h2>Sollte die Wetterstation nicht starten, bitte in 20 Sek. wieder mit dem WLAN Wetterstation verbinden und diese Seite neu aufrufen.</h2></div>");
    } else {
      s.replace("*mark1begin*", "");
      s.replace("*mark1end*", "");
      s.replace("*feedback*", "");
      s.replace("*ssid*", preferences.getString("ssid", ""));
      s.replace("*password*", preferences.getString("password", ""));
      s.replace("*ntpserver*", preferences.getString("ntpserver", ""));
    }
    request->send(200, "text/html", s);
    if (gotAnswer) {
      delay(3000);
      ESP.restart();
    }

  }); 
  server.begin();        // Server start
  Serial.println("HTTP-Server gestartet");

  serverLoop();
}

// ### Eine einfache Schleife zur Anzeige des Status auf dem seriellen Monitor, dass der WLAN-Manager läuft
void serverLoop() {
  while (true) {
    delay(1000);
    Serial.println("WLAN-Netzwerk Wetterstation waehlen und 192.168.4.1 im Browser starten ...");
  }
}
